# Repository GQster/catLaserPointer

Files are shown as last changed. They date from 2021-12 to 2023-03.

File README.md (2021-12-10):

# catLaserPointer
This is a robot that tracks and points a laser for a cat.
It does this by using a raspberry pi 3B+ as the brain, 3d printed parts, two DF9GMS servos, a usb camera, and a laser.

It tracks the cat by using a python script with opencv and an SSD model. 
I followed this guide for the object detection: https://core-electronics.com.au/tutorials/object-identify-raspberry-pi.html 

The CAD files and code are here. 

Pins used on the Pi: 

  pinLaser = 5    # Laser     
  
  pinBase = 12    # Base servo
  
  pinCam = 13     # Camera sevo

Basically the code works by detecting the object, drawing a bounding box on the object, finding its center, then trying to center the object in the image by using the servos. 
Right when the object is detected it turns on the laser. 
After "waitForScan" seconds (10 right now) the robot turns off the laser and scanns the room for objects. 

With my current setup there is about a 3.5 second lag. This is down from ~33 seconds.

Improvments:
  -Decrease lag, 
  -Improve motor contorl to allow for bigger steps depending on how far off center the object is from the image
  -Different robot physical design to increase its workspace

Its view




*NOTE: These are the GPIO.BCM pins

**NOTE: Down around line 340- 350 of "v2CatPointer.py" you can set which objects the robot should detect in "objects= ['cat', 'dog', 'person'] of getObjects() and searchforobject(). There are many different options saved in the "coco.names" file. 

***NOTE: I measured and cadded all the models so they might not be exact. That said I'm fairly sure they are accurate as everything works when basing the measurments off them.

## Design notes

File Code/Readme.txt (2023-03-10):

Readme

Three versions: 1) v2CatPointer.py 
                2) v2CatPointerLAPTOPVERSION.py
                3) *full laptop version*

1) The first uses the GPIO of the raspberry pi 3b so will not run on a normal computer. 
It uses the following libraries:
    cv2
    RPi.GPIO as GPIO
    time

2) The second is a stripped version of the first with all GPIO references removed. 
This means it will not move the motors or control the laser. 
It will still output the captured video; displaying the detected object, its center, its quadrant, and what it is telling the motors to do.
This will run on a normal computer with the following  libraries:
    cv2

NOTE*: Reworked v2CatPointer.py to fully run on a laptop using a teensy to control the motors. Can be found here: https://github.com/grantcroft/AutoTracker/blob/main/autoTracker.py

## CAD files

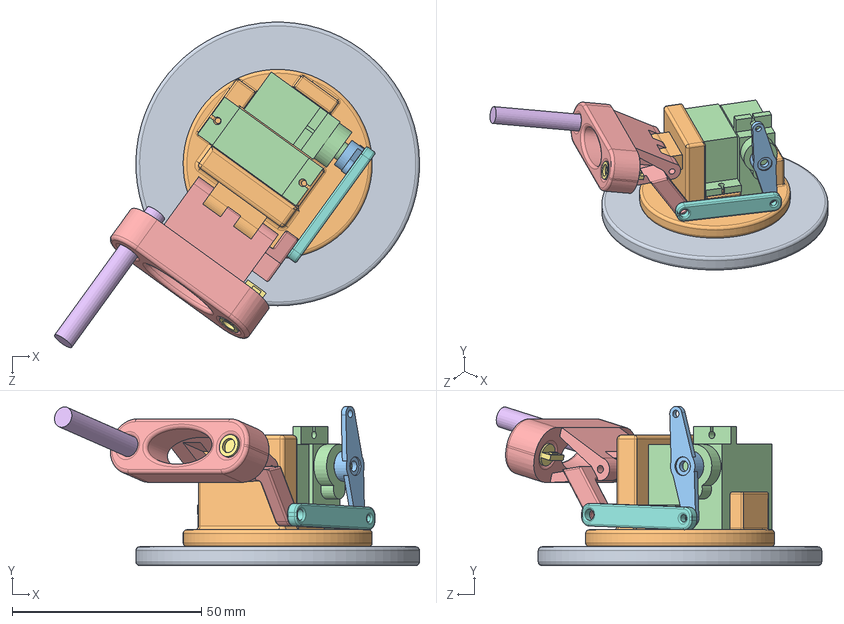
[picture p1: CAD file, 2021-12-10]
SolidworksDesign/Assem.SLDASM
96.5 x 42.1 x 86.1 mm
Base
Top
motor_arm x 2
DF9GMS_servo x 2
CamMount
USB_CAM
LaserDiode
ControlArm_LONG

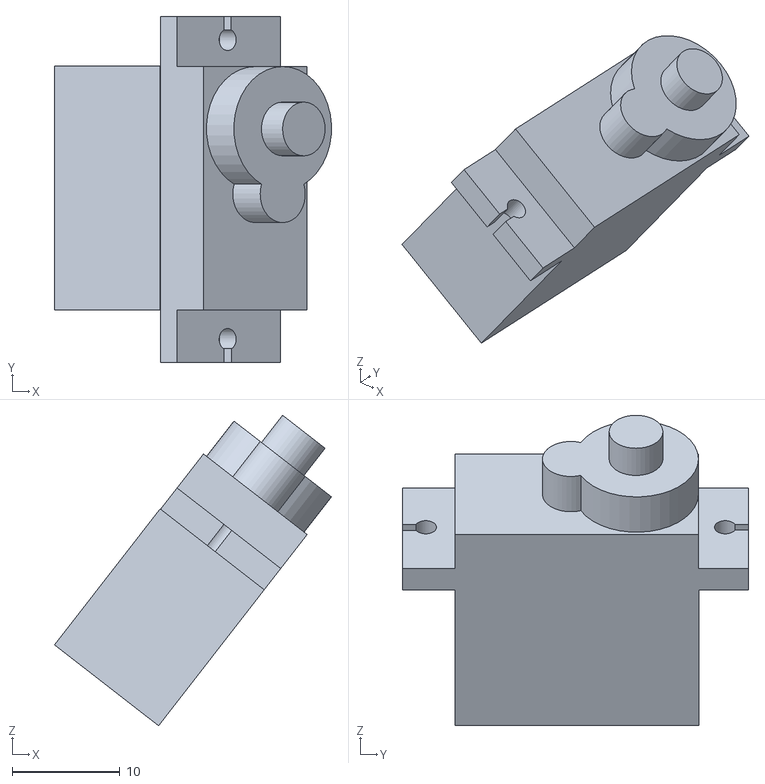
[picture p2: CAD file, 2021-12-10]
SolidworksDesign/STLs/CatV2.1 - Base-1 - DF9GMS_servo-2.STL
25.7 x 32.1 x 28.8

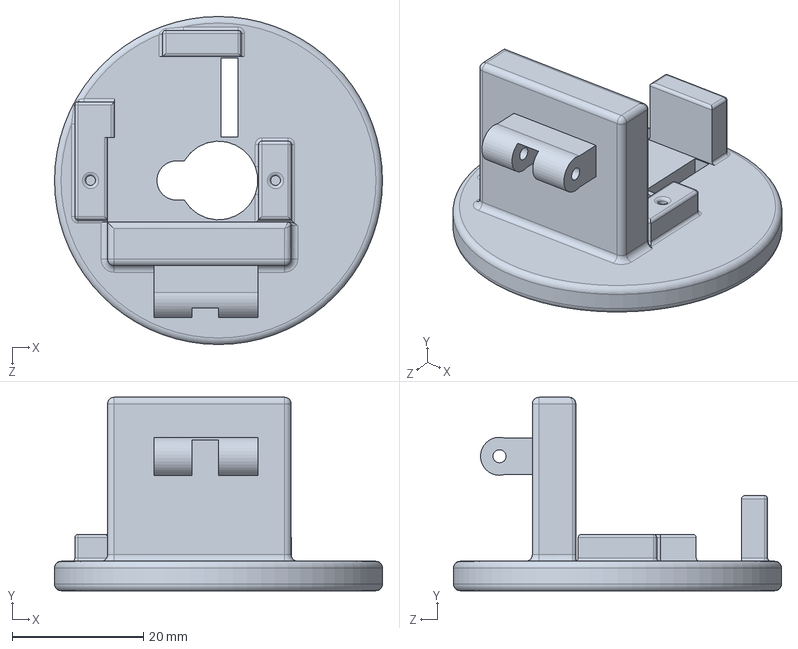
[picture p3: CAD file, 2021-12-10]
SolidworksDesign/Top.SLDPRT
50.0 x 29.5 x 50.0 mm

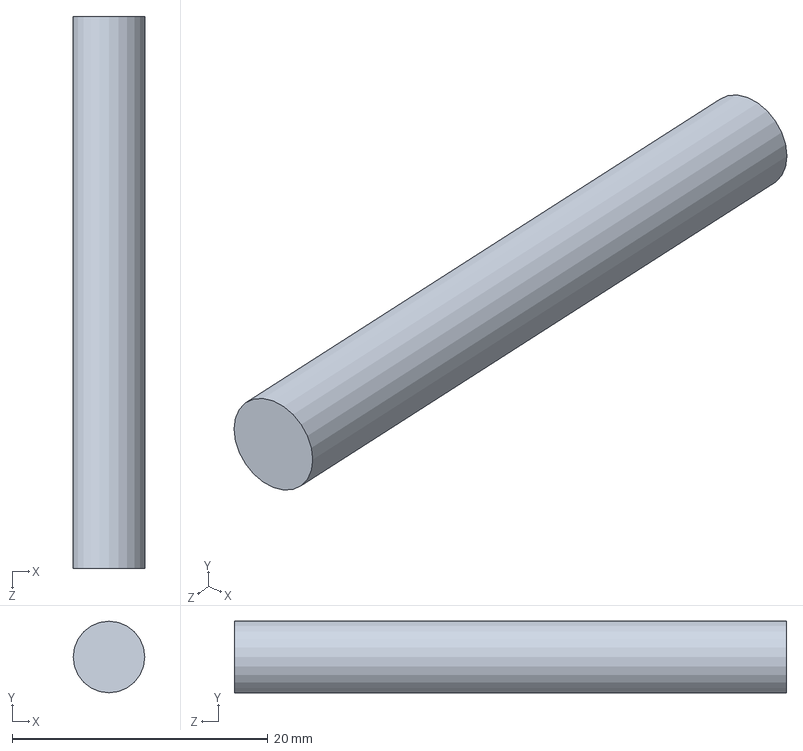
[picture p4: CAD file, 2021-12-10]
USB_CAM.SLDPRT
5.60 x 5.60 x 43.2 mm

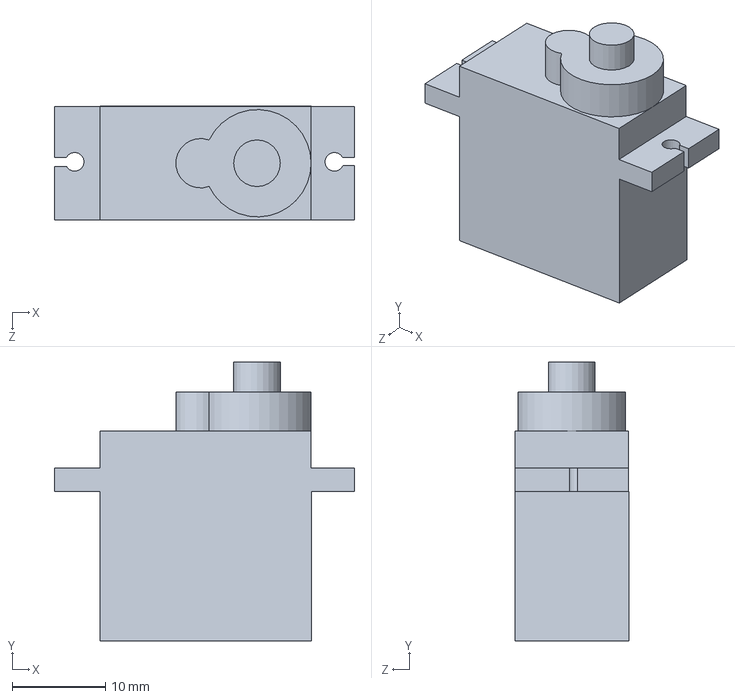
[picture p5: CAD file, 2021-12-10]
DF9GMS_servo.SLDPRT
32.1 x 29.9 x 12.2 mm

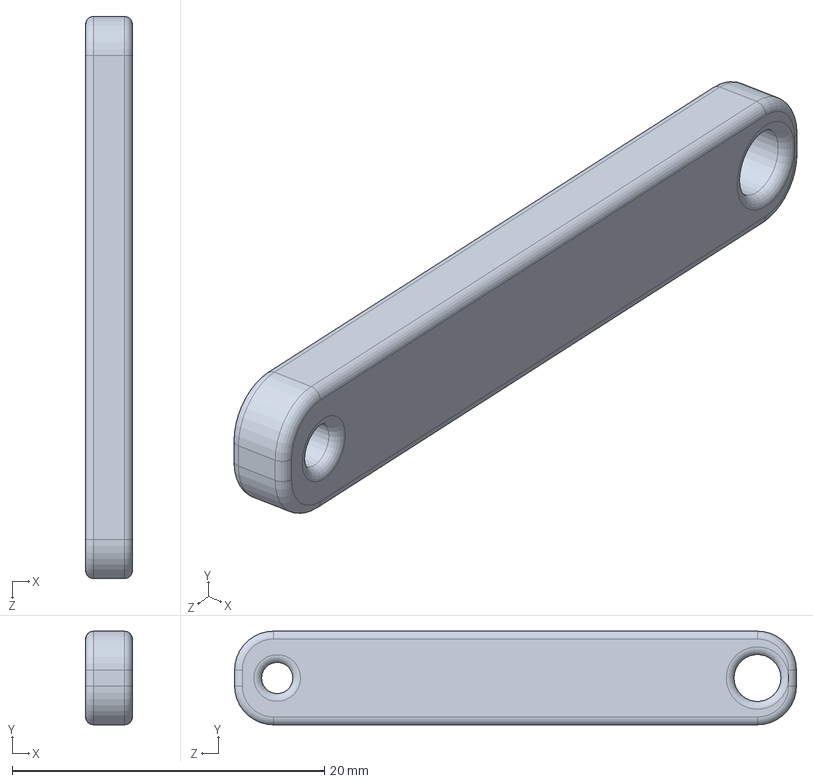
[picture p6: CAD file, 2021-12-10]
SolidworksDesign/ControlArm_LONG.SLDPRT
3.00 x 6.00 x 36.0 mm

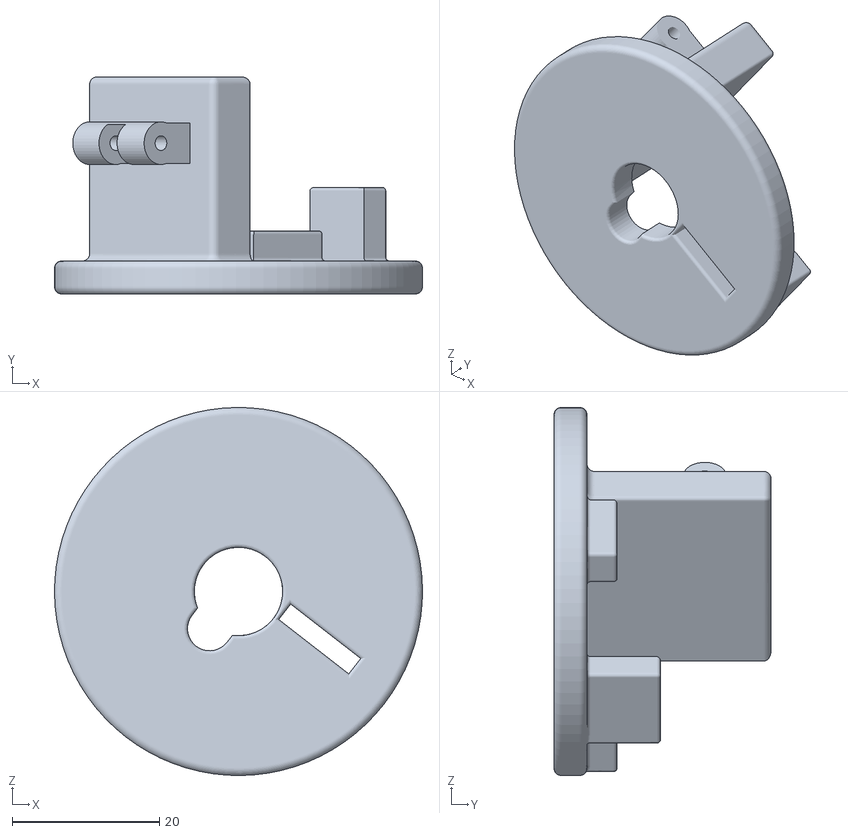
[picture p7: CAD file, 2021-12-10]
SolidworksDesign/STLs/CatV2.1 - Base-1 - Top-1.STL
50.0 x 29.5 x 50.0

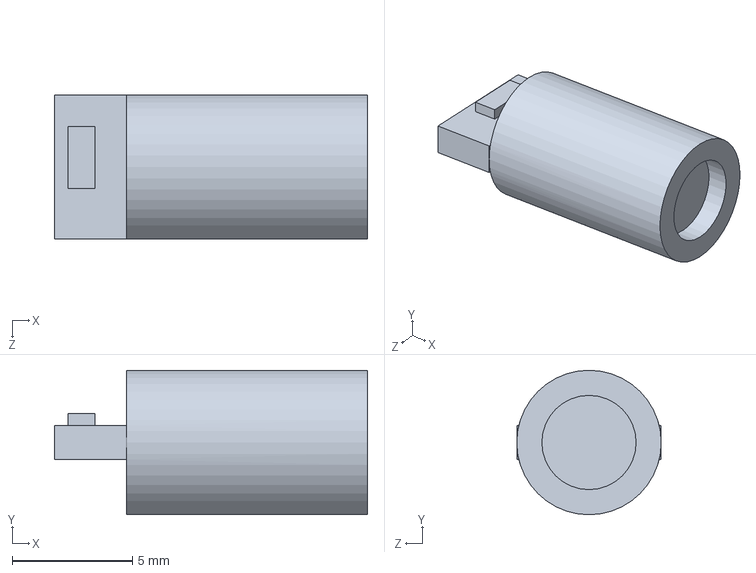
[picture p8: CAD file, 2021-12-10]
LaserDiode.SLDPRT
13.0 x 6.00 x 6.00 mm

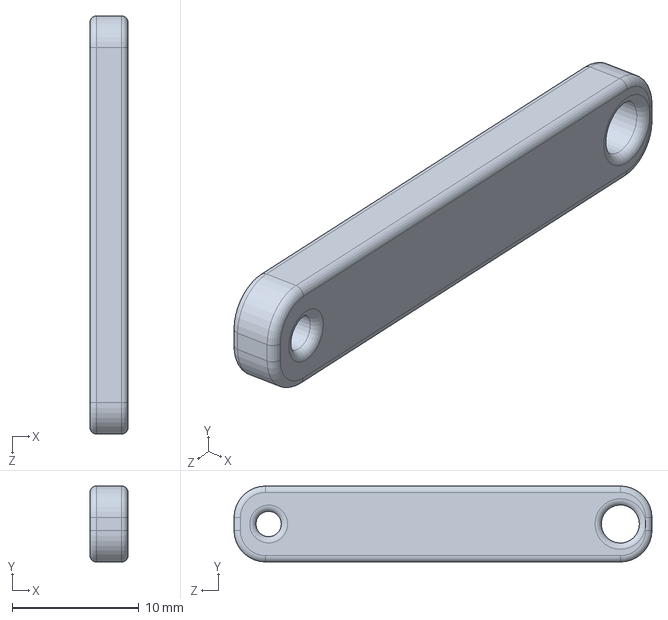
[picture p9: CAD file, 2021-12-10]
SolidworksDesign/ControlArm.SLDPRT
3.00 x 6.00 x 33.0 mm

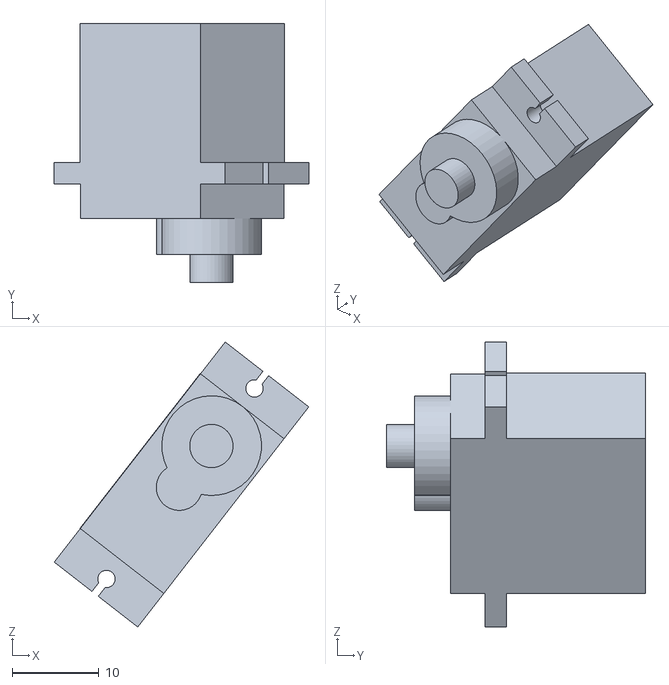
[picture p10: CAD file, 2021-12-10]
SolidworksDesign/STLs/CatV2.1 - Base-1 - DF9GMS_servo-1.STL
29.4 x 29.9 x 32.9

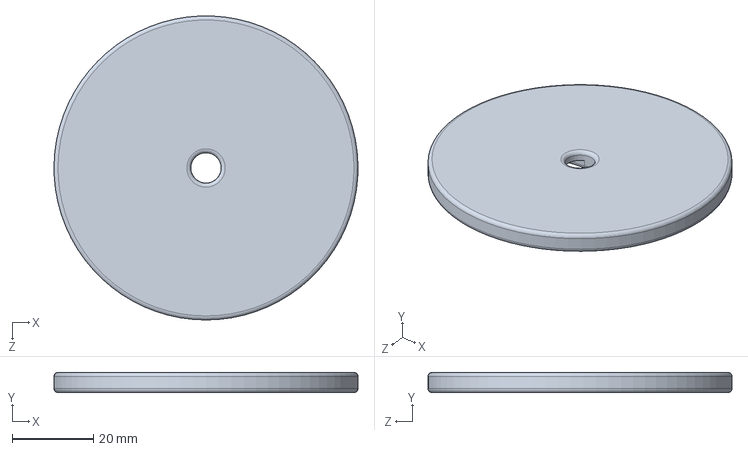
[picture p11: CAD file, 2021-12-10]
SolidworksDesign/Base.SLDPRT
75.0 x 5.00 x 75.0 mm

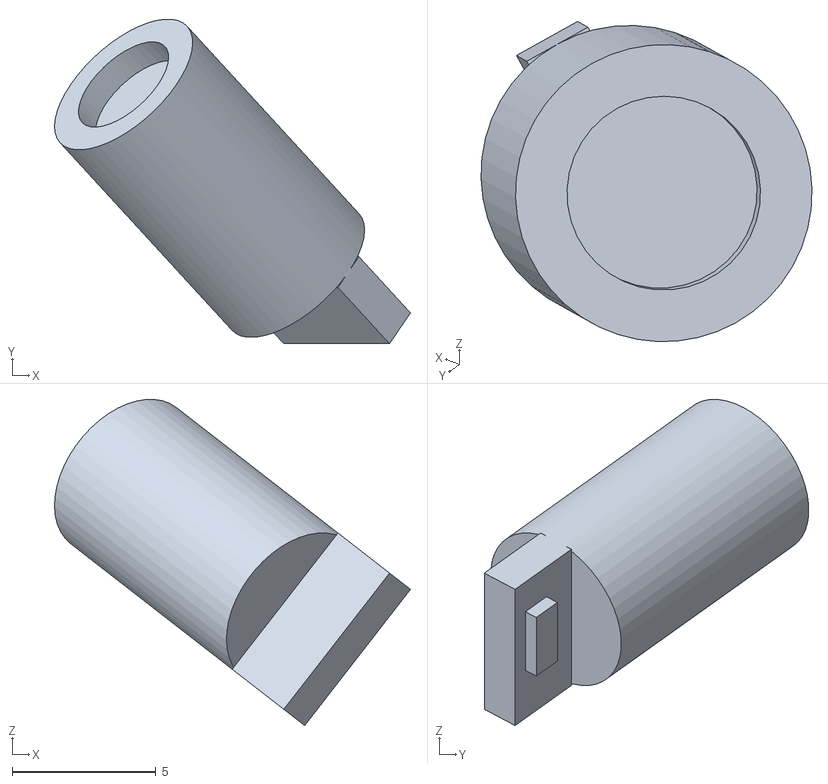
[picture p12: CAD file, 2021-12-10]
SolidworksDesign/STLs/CatV2.1 - Base-1 - LaserDiode-1.STL
12.4 x 11.3 x 11.3

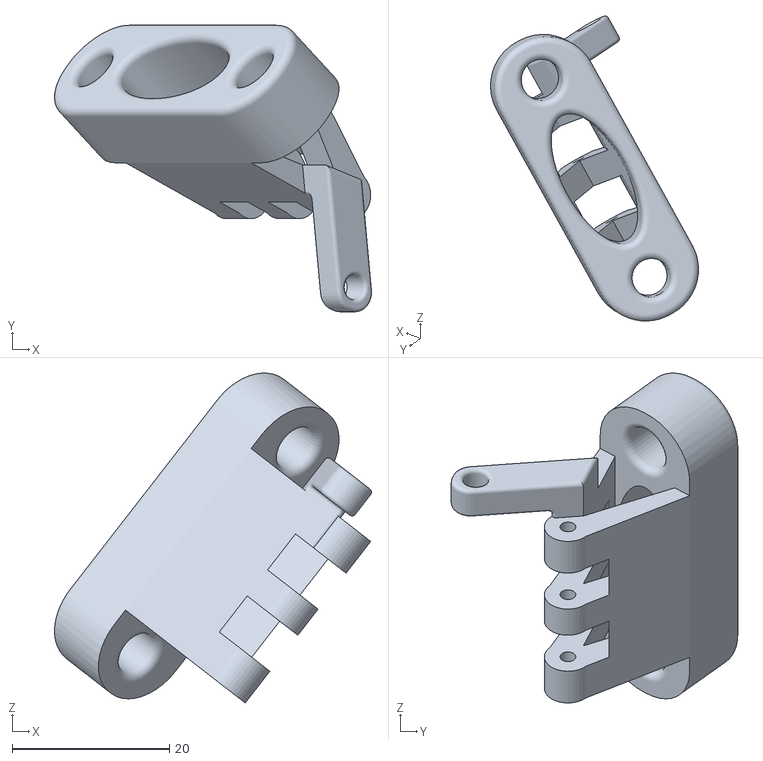
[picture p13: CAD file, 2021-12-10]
SolidworksDesign/STLs/CatV2.1 - Base-1 - CamMount-1.STL
40.3 x 36.4 x 41.9

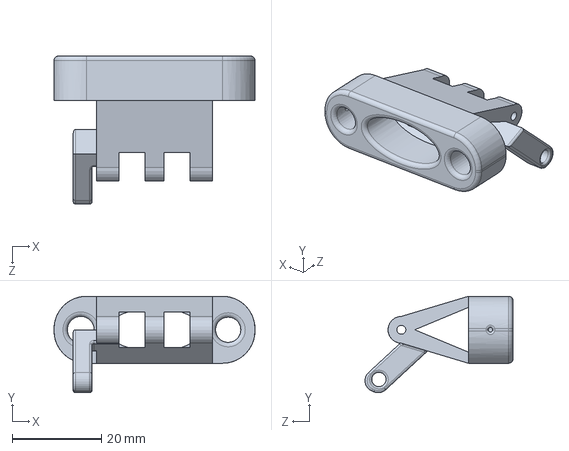
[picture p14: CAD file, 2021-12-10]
SolidworksDesign/CamMount.SLDPRT
45.0 x 21.6 x 33.2 mm

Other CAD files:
SolidworksDesign/STLs/CatV2.1 - Base-1 - motor_arm-1.STL
SolidworksDesign/STLs/CatV2.1 - Base-1 - ControlArm-1.STL
SolidworksDesign/STLs/CatV2.1 - Base-1 - Base-1.STL
SolidworksDesign/STLs/CatV2.1 - Base-1 - motor_arm-2.STL
SolidworksDesign/STLs/CatV2.1 - Base-1 - USB_CAM-1.STL
SolidworksDesign/STLs/ControlArm_LONG.STL

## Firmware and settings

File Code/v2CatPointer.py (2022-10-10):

#****************************************************************
#   Coder: Grant Croft (gxc9140)
#   RIT 585 Principles of Robotics final project
#   This is a cat laser pointer project and can be found on: https://github.com/grantcroft/catLaserPointer/blob/main/README.md 
#
#	For slightly less lag, comment out the .imshow and .waitKey on lines 344 & 345
#****************************************************************
import cv2
import RPi.GPIO as GPIO                                         # Import RPi.GPIO module
import time

# GPIO Pins
pinLaser = 5                                                    # Pin 5 is GPIO 5
pinBase = 12
pinCam = 13

# Motor Control Variables
startAngleC = 70        #45 for wal mount, 90 for floor
camAngle = startAngleC                                          # Keeps track of camera servo angle
startAngleB = 90
baseAngle = startAngleB                                         # Keeps track of camera servo angle
camChange = 2                                                   # How big each sep it (degrees)
baseChange = 2                                                  # How big each sep it (degrees)
baseSearchChange = 5
camUpperBound = 100                                             # Upper bound on camera motor
moveWaitTime = 0.02                                             # How long program waits for servos to move

# Imave Control Varibales
imageW = 640
imageH = 480
camFPS = 30#15#
imageCapW = 160#320#177#
imageCapH = 120#240#144#

# searchforobject() Variables
noObjFound = False
leftSideFLAG = False
rightSideFLAG = False
waitForScan = 10                                                                                                # How long to wait before starting to scan the area for the object

classFile = "/home/pi/Projects/objDetection/coco.names"
weightsPath = "/home/pi/Projects/objDetection/frozen_inference_graph.pb"
configPath = "/home/pi/Projects/objDetection/ssd_mobilenet_v3_large_coco_2020_01_14.pbtxt"
classNames = []
timeCatLastSeen = 0.0

with open(classFile,"rt") as f:
    classNames = f.read().rstrip("\n").split("\n")


net = cv2.dnn_DetectionModel(weightsPath,configPath)
net.setInputSize(imageCapW,imageCapH)
net.setInputScale(1.0/ 127.5)
net.setInputMean((127.5, 127.5, 127.5))
net.setInputSwapRB(True)








def GPIOSetup():
    global pinLaser, pinCam, pinBase

    print("Setting up the GPIO")
    GPIO.setmode(GPIO.BCM)                                      # Choose BCM (GPIO #) or BOARD  (# on board [DIFFERENT PER BOARD])
    GPIO.setwarnings(False)                                     # Disable GPIO Warnings
    GPIO.setup(pinLaser, GPIO.OUT)                              # Set a port/pin as an output
    GPIO.output(pinLaser, 1)                                    # Start with laser off

    print("Going to Starting point")
    GPIO.setup(pinCam,GPIO.OUT)
    servoCam = GPIO.PWM(pinCam, 50)
    servoCam.start(0)
    servoCam.ChangeDutyCycle(2+(startAngleC/18))                # Start camera at 45 degrees (parallel with mounting surface)
    time.sleep(0.15)                                            # Let motor move
    servoCam.ChangeDutyCycle(0)

    GPIO.setup(pinBase,GPIO.OUT)
    servoBase = GPIO.PWM(pinBase, 50)
    servoBase.start(0)
    servoBase.ChangeDutyCycle(2+(startAngleB/18))               # Start camera at 90 degrees
    time.sleep(0.15)                                            # Let motor move
    servoBase.ChangeDutyCycle(0)

    return servoCam, servoBase


def laserOnOff(onOff, pin):   # Turns laser on and off with '0' and '1' input
        if onOff == 0:
                GPIO.output(pin, 1)                             # Turn OFF
        elif onOff == 1:
                GPIO.output(pin, 0)                             # Turn ON
        return


def findQuad(objCenterX, objCenterY):
    global imageW, imageH

    x_half = (int(imageW/2))
    y_half = (int(imageH/2))
    if (objCenterX >= x_half):
        if (objCenterY <= y_half):                                      # quad #1
            quadrant = 1
            print("Animal is too high")
            print("Animal is too far RIGHT")
        elif(objCenterY > y_half):                                      # quad #4
            quadrant = 4
            print("Animal is too low")
            print("Animal is too far RIGHT")

    elif (objCenterX < x_half):
        if (objCenterY <= y_half):                                      # quad #2
            quadrant = 2
            print("Animal is too high")
            print("Animal is too far LEFT")
        elif (objCenterY > y_half):                                     # quad #3
            quadrant = 3
            print("Animal is too low")
            print("Animal is too far LEFT")
    else:
        print("ERROR, INVALID CENTER LOCATION")
        quadrant = 0

    return quadrant


def motorMove(Xc, Yc, servoC, servoB, quadSector, allowMotion=True):     # Moves the two motors
    global camAngle, baseAngle, camChange, baseChange, camUpperBound, moveWaitTime

    if allowMotion:
                # Cam servo contorl
        if Yc != imageH/2:
            if quadSector == 1 or quadSector == 2:
                camAngle -= camChange                           # decrease servo angle
                if camAngle <= 0:
                    camAngle = 1
                    print("Cam angle boundary: 0 deg")
                servoC.ChangeDutyCycle(2+(camAngle/18))         # Change cam angel
                time.sleep(moveWaitTime)                        # Let motor move
                servoC.ChangeDutyCycle(0)
            elif quadSector == 3 or quadSector == 4:
                camAngle += camChange                           # increase servo angle
                if camAngle >= camUpperBound:
                    camAngle = camUpperBound
                    print("Cam angle boundary: ", camUpperBound, " deg")
                servoC.ChangeDutyCycle(2+(camAngle/18))         # Change cam angel
                time.sleep(moveWaitTime)                        # Let motor move
                servoC.ChangeDutyCycle(0)


                # Base servo control
        if Xc != imageW/2:
            if quadSector == 1 or quadSector == 4:
                baseAngle -= baseChange                         # decrease servo angle
                if baseAngle <= 0:
                    baseAngle = 1
                    print("Base angle boundary: 0 deg")
                servoB.ChangeDutyCycle(2+(baseAngle/18))        # Change base angel
                time.sleep(moveWaitTime)                        # Let motor move
                servoB.ChangeDutyCycle(0)

            elif quadSector == 2 or quadSector == 3:
                baseAngle += baseChange                         # increase servo angle
                if baseAngle >= 180:
                    baseAngle = 179
                    print("Base angle boundary: 180 deg")
                servoB.ChangeDutyCycle(2+(baseAngle/18))        # Change base angel
                time.sleep(moveWaitTime)                        # Let motor move
                servoB.ChangeDutyCycle(0)

    else:
        print("Motion not allowed")
        servoB.ChangeDutyCycle(0)
        servoC.ChangeDutyCycle(0)
    return

def searchforobject(img, thres, nms, servoC, servoB, draw=True, objects=[]):
    global baseAngle, baseChange, moveWaitTime, timeCatLastSeen, leftSideFLAG, rightSideFLAG
        #global camAngle, camChange, camUpperBound,

    if baseAngle <= baseSearchChange:
        print("Left point reached")
        leftSideFLAG = True
    if baseAngle >= (180-baseSearchChange):
        print("Right point reached")
        rightSideFLAG = True

    if leftSideFLAG and rightSideFLAG:
        print("Area searched, no object found.")
        rightSideFLAG = False
        leftSideFLAG = False

    if leftSideFLAG:                                                                    # Search going right
        baseAngle += baseSearchChange                   # Increase servo angle
        servoB.ChangeDutyCycle(2+(baseAngle/18))        # Change base angel
        time.sleep(moveWaitTime)                        # Let motor move
        servoB.ChangeDutyCycle(0)
        print("Searching right for object. Base angle: {}".format(baseAngle))

    elif baseAngle > baseSearchChange:                                  # Search going left
        baseAngle -= baseSearchChange                   # decrease servo angle
        servoB.ChangeDutyCycle(2+(baseAngle/18))        # Change base angel
        time.sleep(moveWaitTime)                        # Let motor move
        servoB.ChangeDutyCycle(0)
        print("Searching left for object. Base angle: {}".format(baseAngle))

    return


def drawOnImg(lineORCenter, pic, classId, confidence, servoC, servoB, box=0):
    if lineORCenter == 'box':
        global classNames
        cv2.rectangle(pic,box,color=(0,255,0),thickness=2)
        cv2.putText(pic,classNames[classId-1].upper(),(box[0]+10,box[1]+30),
        cv2.FONT_HERSHEY_COMPLEX,1,(0,255,0),2)
        cv2.putText(pic,str(round(confidence*100,2)),(box[0]+200,box[1]+30),
        cv2.FONT_HERSHEY_COMPLEX,1,(0,255,0),2)

    if lineORCenter == 'line':                              # Draw grid on image
        global imageW, imageH

        x_half, x_L, x_R = int(imageW/2), 0, imageW
        y_half, y_bot, y_top = int(imageH/2), 0, imageH
        cv2.line(pic, (x_half, y_bot), (x_half, y_top), (0, 0, 200), thickness=1)
        cv2.line(pic, (x_L, y_half), (x_R, y_half), (0, 0, 200), thickness=1)

    if lineORCenter == 'center':                            # Finds center of object
        Xtl, Ytl = box[:2]
        Xcenter = Xtl + (box[2]/2)
        Ycenter = Ytl + (box[3]/2)
        center_coordinates = (int(Xcenter), int(Ycenter))
        cv2.circle(pic, center_coordinates, radius=5, color=(255, 255, 0), thickness=5)
        #print(Xcenter ," <<<X, Y>>> " , Ycenter)
        quad = findQuad(Xcenter, Ycenter)
        print(quad)
        motorMove(Xcenter, Ycenter, servoC, servoB, quad, True)        # Moves the motors
    return


def getObjects(img, thres, nms, motorY, motorX, draw=True, objects=[]):
    global imageW, imageH, timeCatLastSeen, noObjFound

    classIds, confs, bbox = net.detect(img,confThreshold=thres,nmsThreshold=nms)
    #print(classIds,bbox)

    if len(objects) == 0: objects = classNames
    objectInfo =[]
    if len(classIds) != 0:
        numOfObjDetected = 0
        for classId, confidence,box in zip(classIds.flatten(),confs.flatten(),bbox):
            className = classNames[classId - 1]
            if className in objects:
                objectInfo.append([box,className])
                noObjFound = False                                                      # Saves that it found an obj
                timeCatLastSeen = time.time()                   # Updates when the cat was last seen
                laserOnOff(1, pinLaser)                         # Turn ON

                numOfObjDetected += 1
                if numOfObjDetected == 2:                       # Makes it return only set num of objs
                    break       #WORKS, BUT MIGHT NOT BE THE OBJ YOU WANT

                if (draw):

                    drawOnImg('box', img, classId, confidence, 0, 0, box)       # Draw bounding box
                    drawOnImg('center', img, classId, confidence, motorY, motorX, box)    # Find center of obj
                    drawOnImg('line', img, classId, confidence, 0, 0)                     # Draw quad grid

    return img,objectInfo


def clean_up(servoC, servoB):                                                                   #Cleans up resources

    print('Shutting down')
    try:
        if cap:
            cap.release()                                   # Release software & hardware resources for 'cap'
            print("Camera released")

        laserOnOff(0, pinLaser)                             #Turn off laser
        print("Laser powered off")

        servoC.ChangeDutyCycle(2+(startAngleC/18))          # Start camera at 90 degrees (parallel with mounting surface)
        time.sleep(0.15)                                    # Let motor move
        servoC.ChangeDutyCycle(0)
        print("Cam position reset")

        servoB.ChangeDutyCycle(2+(startAngleB/18))          # Start camera at 90 degrees (parallel with mounting surface)
        time.sleep(0.15)                                    # Let motor move
        servoB.ChangeDutyCycle(0)
        print("Base motor powered off")

        GPIO.cleanup()
        print("GPIO clean up finished!!! Bye\n\n")

    except Exception:
        print('Error while shutting down')
    return



if __name__ == "__main__":
    #Setup:
    timeCatLastSeen = time.time() 
    
    print("Hello, starting up the cat laser pointer!")
    sCamObj, sBaseObj = GPIOSetup()                             # Creating Camera Servo object and DC motor object

    print("Turning on camera")
    cap = cv2.VideoCapture(0)
    cap.set(3,imageCapW)                                        # Width of the frames in the video stream.
    cap.set(4,imageCapH)                                        # Height of the frames in the video stream.
    cap.set(5, camFPS)                                          # Frame rate.
    # https://docs.opencv.org/3.0-beta/modules/videoio/doc/reading_and_writing_video.html#videocapture-set      <<< VideoCapture doc

    # Info on USB probe camera being used:
    #$ v4l2-ctl -d /dev/video0 --list-formats-ext
    # OUTPUT: [0]: 'YUYV' (YUYV 4:2:2) Resolution: 640x480, 352x288, 320x240, 176x144, 160x120 All at 15 & 30 FPS

#Test Rsutls:   #using .imshow slows it down about a second
    # RES       LAG 30 FPS      LAG 15 FPS
    #640x480    33 sec          34 sec
    #352x288    13 sec          13.7 sec
    #320x240    8.3 sec         8.0
    #176x144    3.75            3.5                     TOO SMALL?
    #160x120    3.0             2.9                     TOO SMALL?

    #BEST: imageCapWH = 160x120, imageW = 640x480; FPS 30: 3.9sec, FPS 15: 3.9sec





    numObj = 0.99 #nms:  nms percentage value, increasing this will limit the amount of simultaneously identified objects
    thresh = 0.45 # Threshold to detect object

    print("Program read")
    while True:
        try:
            success, img = cap.read()
            img = cv2.resize(img, (imageW, imageH))
            result, objectInfo = getObjects(img, thresh, numObj, sCamObj, sBaseObj, objects=['cat', 'dog', 'person'])   # 'cat', 'dog', 'person'
            cv2.imshow("Output",img)
            cv2.waitKey(1)

            if (time.time() - waitForScan) > timeCatLastSeen:   # Checks if the cat was seen within "waitForScan" seconds
                noObjFound = True
                laserOnOff(0, pinLaser)                         # Turn off laser
                searchforobject(img, thresh, numObj, sCamObj, sBaseObj, objects=['cat', 'dog', 'person'])                               # 'cat', 'dog', 'person'
#                motorMove(0, 0, sCamObj, sBaseObj, 0, False)   # Stop Motors

            if noObjFound:
                print("Object not found for ", int(time.time()-timeCatLastSeen), " seconds.")                   # DOESNT WORK QUITE RIGHT... IF NEVER FOUND OBJECT PRINTS HUGE NUMBER


        except KeyboardInterrupt:
            print('Exiting...')
            clean_up(sCamObj, sBaseObj)

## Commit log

2021-12-10 Add files via upload
    Robot Cad
    [Assem1.SLDASM, BEARING.SLDPRT, DF9GMS_servo.SLDPRT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]
2021-12-10 Delete solidworks Design-V2 directory
    wrong cad
    [Assem1.SLDASM, BEARING.SLDPRT, DF9GMS_servo.SLDPRT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]
2021-12-10 Add files via upload
    V3 cad
    [Assem.SLDASM, Base.SLDPRT, CamMount.SLDPRT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]
2022-10-10 fixed object not found in x time thing
    [v2CatPointer.py]
2023-03-10 linked laptop/teensy git repo version
